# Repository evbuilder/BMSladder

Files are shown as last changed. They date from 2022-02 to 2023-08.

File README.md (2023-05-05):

# BMSladder
-----------
 BMS - cell at a time

This is an attempt at a single cell daisy chain Battery Management System. Emphasis is placed on minimum power draw and cost. Hopefully it is also reliable.

Most parts are over specified, however I worry that having the microcontroller powered directly from the cell could lead to bad things if the cell ever has a voltage spike on it. The type caused by a loose connection maybe especially bad.

Be warned.

Flashing the microcontroller
----------------------------
This uses a newer generation of ATtiny that is commonly used with Arduino. Current firmware uses Microchip Studio, and I have used a ATtiny416xplained demo board to flash the ATtiny202
Alternatively, firmware could be developed that uses Arduino IDE, with a programmer made as described here: https://github.com/SpenceKonde/AVR-Guidance/blob/master/UPDI/jtag2updi.md

History:
--------

v1.1
- incorporate uC pin swap mod
- improve connections

v1.0 Initial test production run. Mostly works. If you ever get one of these boards, check to see the modification is done to swap FAULT and EN pins.

Application: KiCad
Version: (5.1.10-1-10_14), release build

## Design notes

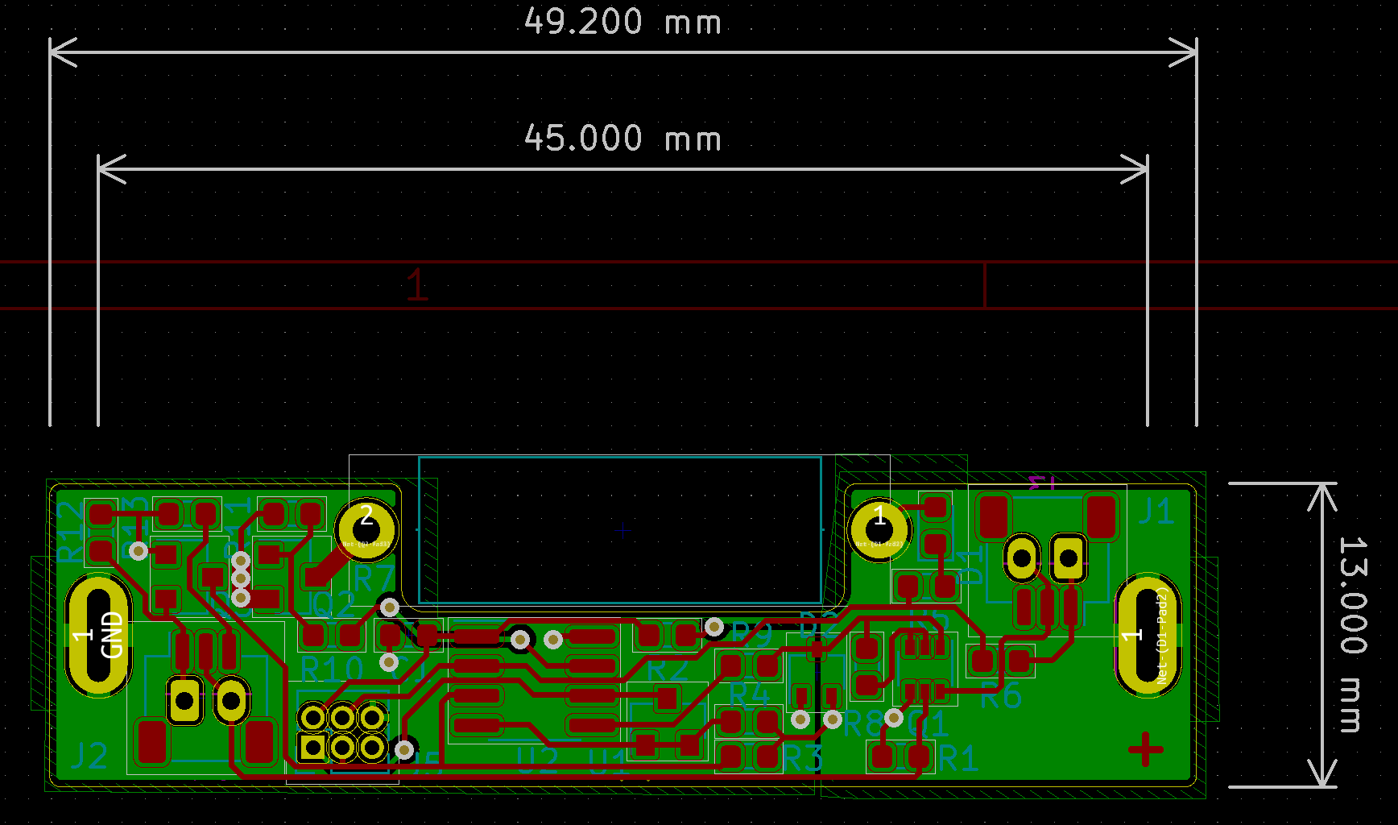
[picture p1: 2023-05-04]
BMSladder_pcb.png

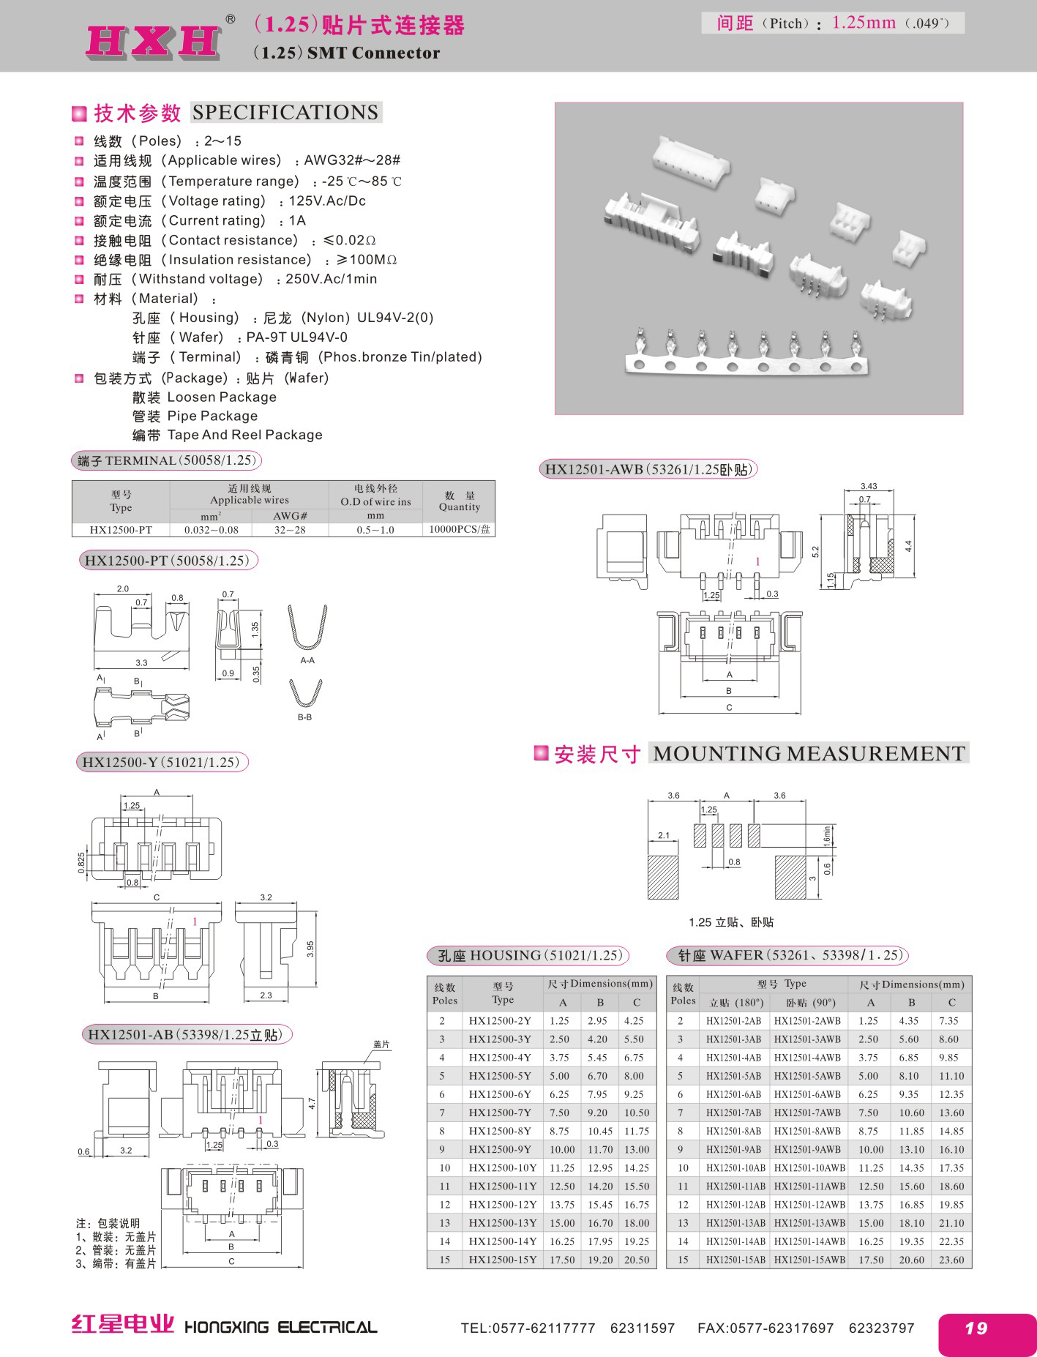
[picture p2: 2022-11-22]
Datasheets/HX12501 1.25mm connector system.jpg

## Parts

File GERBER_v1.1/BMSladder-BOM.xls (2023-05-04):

Designation | Designator | Footprint
SM03B-SRSS-TB(LF)(SN) | J1,J2 | JST_SH_SM03B-SRSS-TB_1x03-1MP_P1.00mm_Horizontal
RED LED | D1 | LED_0603_1608Metric
220k | R3,R8,R9,R11 | R_0603_1608Metric
ATTINY-202SSF | U2 | SOIC-8_3.9x4.9mm_P1.27mm
270k | R13 | R_0603_1608Metric
150k | R1,R6,R12 | R_0603_1608Metric
3K3 | R4,R5,R10 | R_0603_1608Metric
10R | R2 | R_0603_1608Metric
MMBT3904 | Q3 | SOT-23
SI3402-TP | Q2 | SOT-23
MMDT3946 | Q1 | SOT-363_SC-70-6
BAV99W | D2 | SOT-323_SC-70
1uF X7R 16V | C1 | C_0603_1608Metric

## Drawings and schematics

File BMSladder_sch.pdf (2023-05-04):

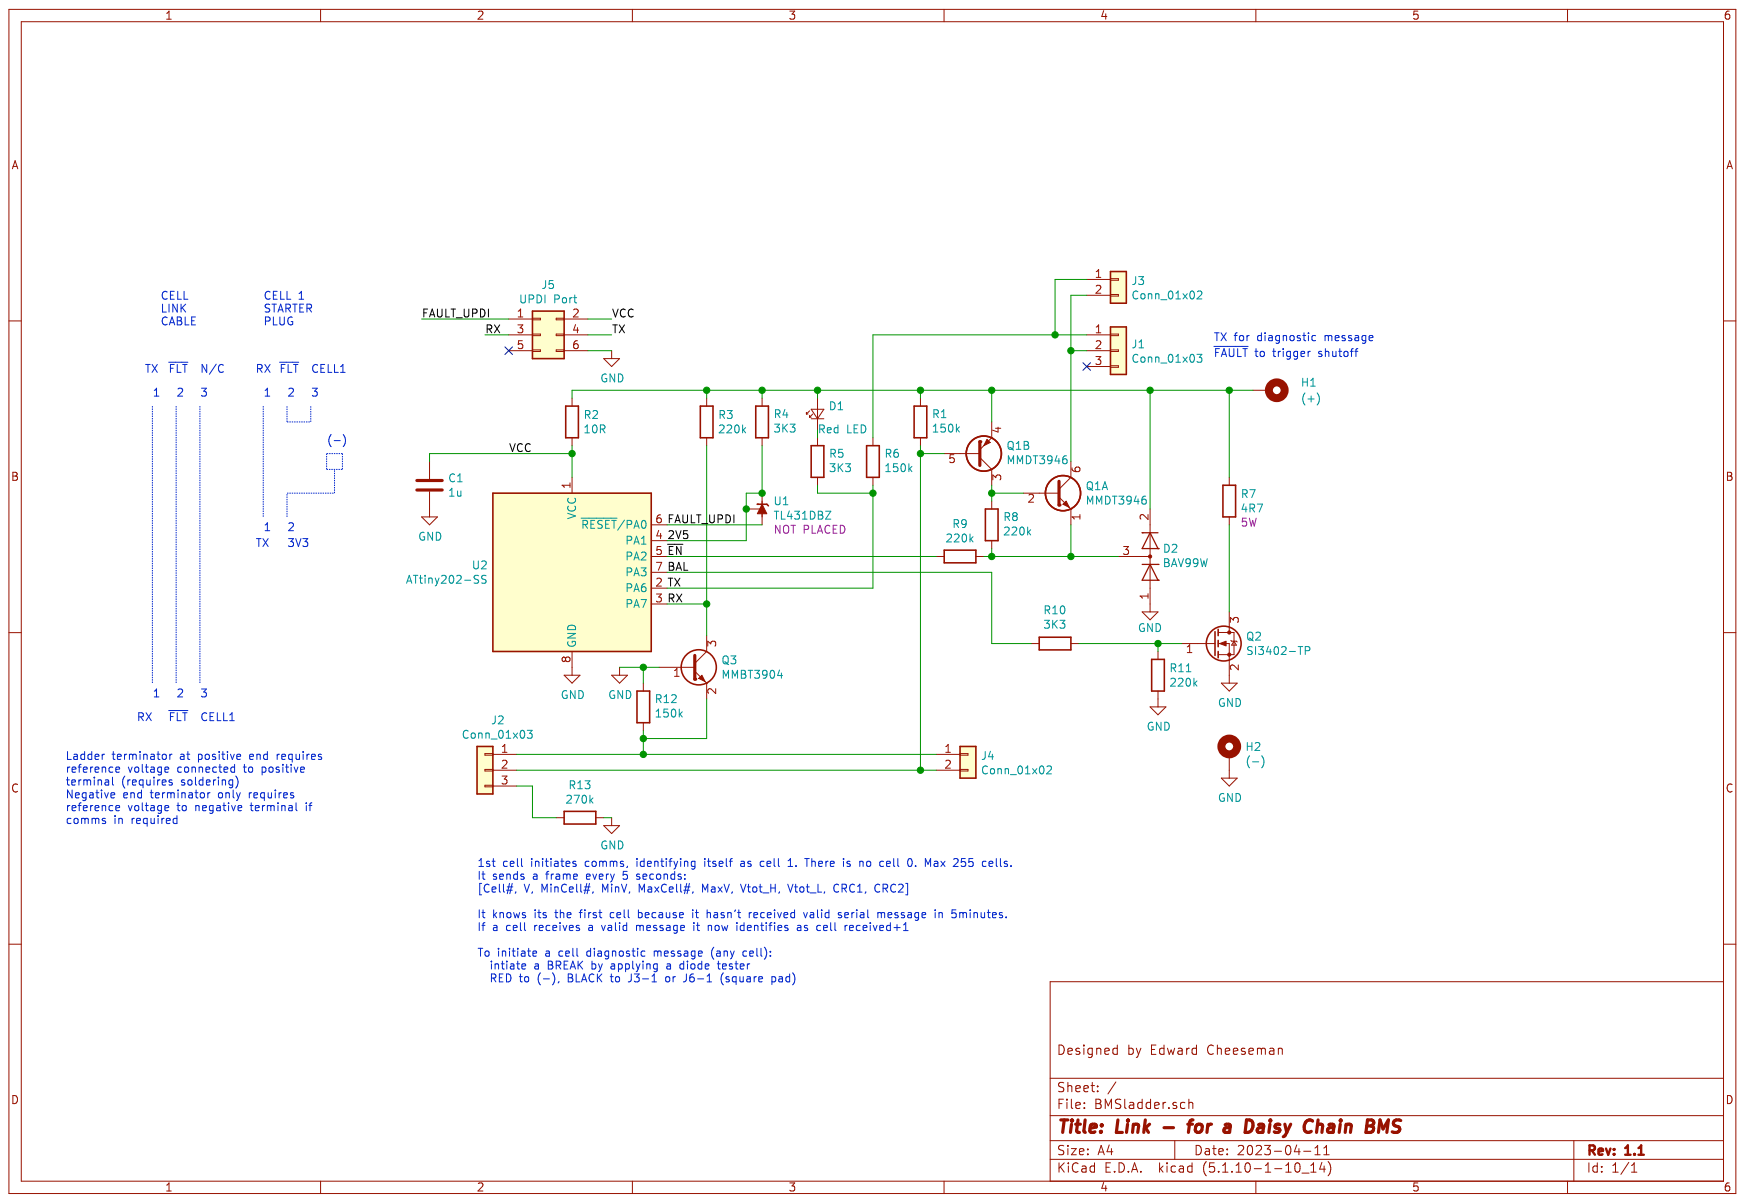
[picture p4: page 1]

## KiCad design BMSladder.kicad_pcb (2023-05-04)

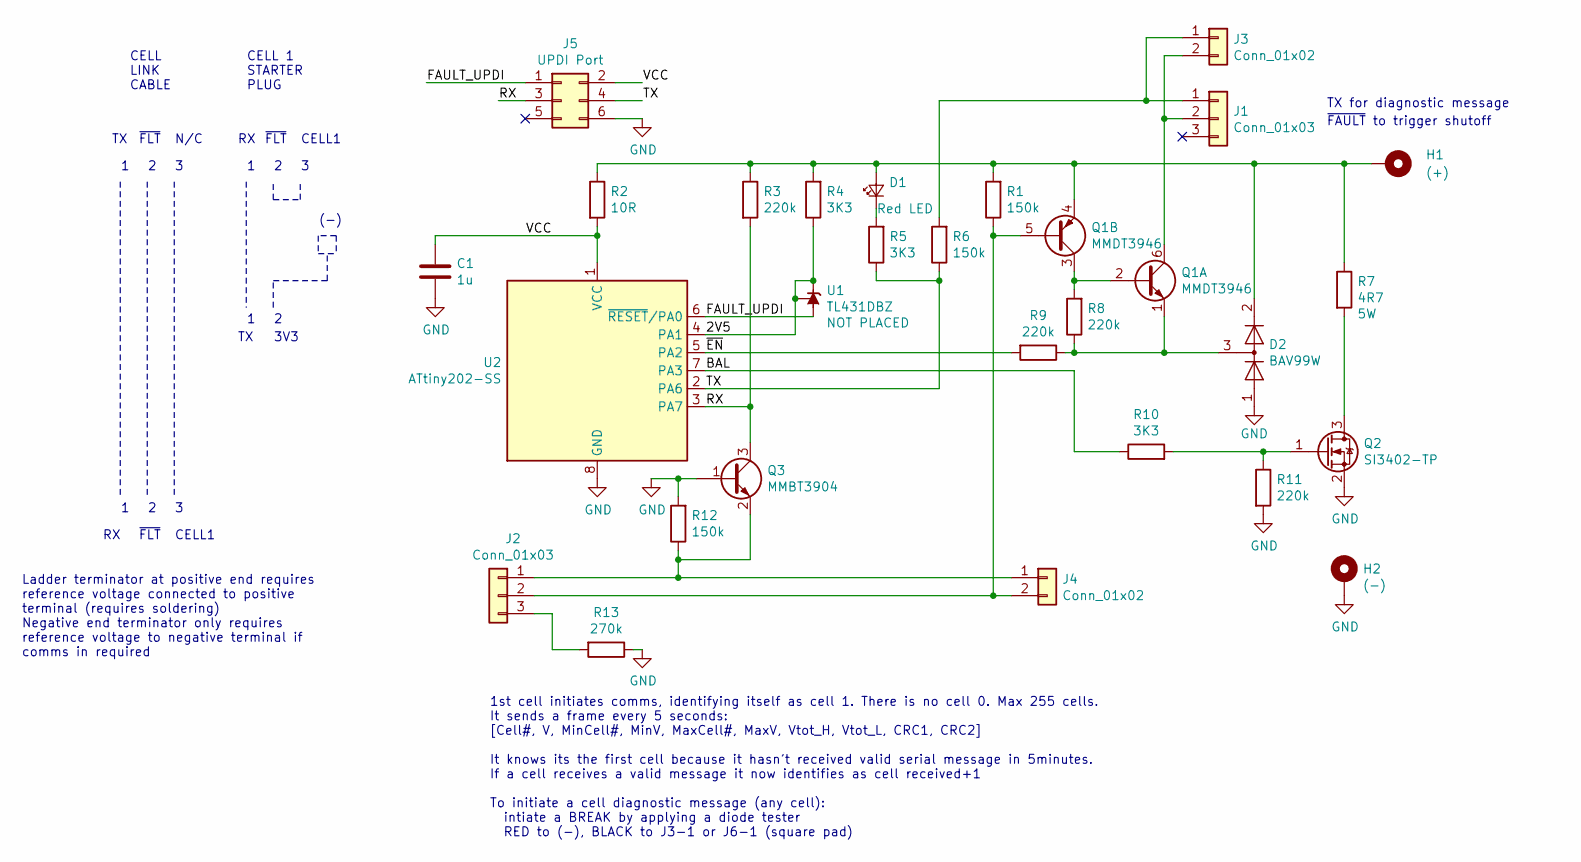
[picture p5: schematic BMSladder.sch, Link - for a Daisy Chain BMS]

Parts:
C1: 1u; C_0603_1608Metric
D1: Red LED; LED_0603_1608Metric
D2: BAV99W; SOT-323_SC-70
H1: (+); Terminal tag 3.2mm slot
H2: (-); Terminal tag 3.2mm slot
J1, J2: Conn_01x03; JST_SH_SM03B-SRSS-TB_1x03-1MP_P1.00mm_Horizontal
J3, J4: Conn_01x02; HY2.0mm2P_Header_Horizontal
J5: UPDI Port; PinHeader_2x03_P1.27mm_Vertical
Q1: MMDT3946; SOT-363_SC-70-6
Q2: SI3402-TP; SOT-23
Q3: MMBT3904; SOT-23
R1, R6, R12: 150k; R_0603_1608Metric
R2: 10R; R_0603_1608Metric
R3, R8, R9, R11: 220k; R_0603_1608Metric
R4, R5, R10: 3K3; R_0603_1608Metric
R7: 4R7; R_Axial_L17.0mm_D6.0mm_P22mm_Horizontal
R13: 270k; R_0603_1608Metric
U1: TL431DBZ; SOT-23
U2: ATtiny202-SS; SOIC-8_3.9x4.9mm_P1.27mm

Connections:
/2V5: R4.1, U1.1 (K), U1.2 (REF), U2.4 (PA1)
/BAL: R10.1, U2.7 (PA3)
/FAULT_UPDI: J5.1, U1.3 (A), U2.6 (~RESET~/PA0)
/RX: J5.3, Q3.3 (C), R3.2, U2.3 (PA7)
/TX: J5.4, R5.1, R6.1, U2.2 (PA6)
/VCC: C1.1, J5.2, R2.2, U2.1 (VCC)
/~EN: R9.2, U2.5 (PA2)
GND: C1.2, D2.1 (K), H2.1, J5.6, Q2.2 (S), Q3.1 (B), R11.2, R12.2, R13.1, U2.8 (GND)
unnamed: D1.1 (K), R5.2
unnamed: D1.2 (A), D2.2 (A), H1.1, Q1.4 (E2), R1.2, R2.1, R3.1, R4.2, R7.1
unnamed: D2.3 (K), Q1.1 (E1), R8.1, R9.1
unnamed: J1.1, J3.1, R6.2
unnamed: J1.2, J3.2, Q1.6 (C1)
unnamed: J2.1, J4.1, Q3.2 (E), R12.1
unnamed: J2.2, J4.2, Q1.5 (B2), R1.1
unnamed: J2.3, R13.2
unnamed: Q1.2 (B1), Q1.3 (C2), R8.2
unnamed: Q2.1 (G), R10.2, R11.1
unnamed: Q2.3 (D), R7.2

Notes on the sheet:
1st cell initiates comms, identifying itself as cell 1. There is no cell 0. Max 255 cells. It sends a frame every 5 seconds: [Cell#, V, MinCell#, MinV, MaxCell#, MaxV, Vtot_H, Vtot_L, CRC1, CRC2] It knows its the first cell because it hasn’t received valid serial message in 5minutes. If a cell rece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
TX for diagnostic message
~FAULT~ to trigger shutoff
N/C
~FLT
CELL1
CELL LINK CABLE
CELL 1 STARTER PLUG
Ladder terminator at positive end requires reference voltage connected to positive terminal (requires soldering) Negative end terminator only requires reference voltage to negative terminal if comms in required
(-)
3V3

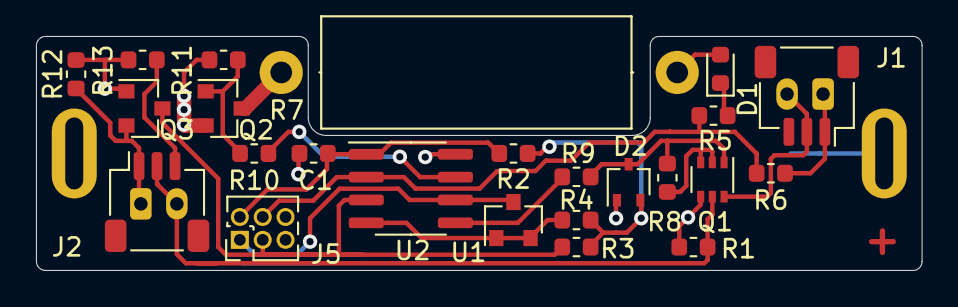
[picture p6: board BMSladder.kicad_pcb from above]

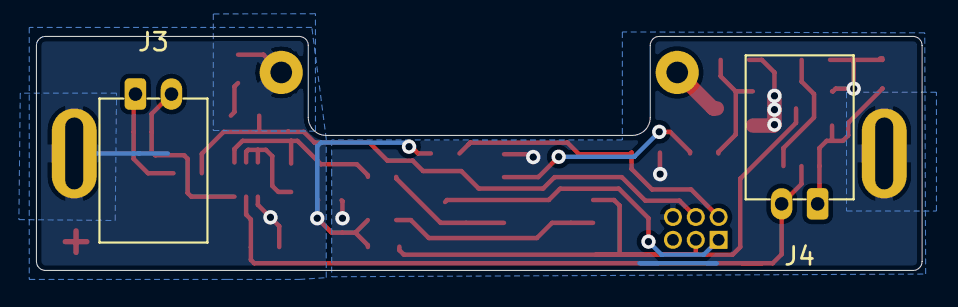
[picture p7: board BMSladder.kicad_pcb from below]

Board: 2 copper layers, 49.2 x 13.0 mm, 28 parts (2 on the bottom side), 19 nets.

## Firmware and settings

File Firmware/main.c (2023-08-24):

/*
	Notes:
	Program written and compiled in Microchip studio V7.0.2542
	
	Fuse Configuration:
	
	BOD - Disabled, when in brown out, the power consumption goes to 100uA vs < 1uA in shutdown sleep mode.
	Reset Pin - Configured for GPIO mode (Note, this makes the chip no longer reprogrammable without getting hold of a 12V pulse programmer
	Watchdog - 8k cycles, 8.2 seconds, this code always runs, then sleeps and waits for the watchdog to trigger a reset, there is no "main loop" for power consumption optimization.
	Startup Time - 16ms
*/

#include <avr/io.h>
#include <stdbool.h>

#include "CellManagement.h"
#include "HardwareDefines.h"

#define F_CPU 3200000UL
#include "util/delay.h"

void InitializeIO(void)
{
	PORTA_PIN0CTRL = PORT_ISC_INPUT_DISABLE_gc;
	PORTA_DIR = BALANCE_PIN_MASK | TX_LED_PIN_MASK;
	PORTA_OUTSET = TX_LED_PIN_MASK; //Default LED state is off	
}

void InitializeBalancePWM()
{
	TCA0_SINGLE_PER = 1024;
	TCA0_SINGLE_CMP0 = 128; //12.5% duty cycle on the balance FET, period around 80ms
	TCA0_SINGLE_CTRLB = TCA_SINGLE_CMP0EN_bm | TCA_SINGLE_WGMODE_SINGLESLOPE_gc;
	TCA0_SINGLE_CTRLA = TCA_SINGLE_CLKSEL_DIV256_gc;
	TCA0_SINGLE_CTRLC = 0;
}

inline void IndicateFault(void)
{
	PORTA_OUTSET = REF2V5_ENABLE_REPURPOSED_AS_FAULT;
}

inline void IndicateNoFault(void)
{
	PORTA_OUTCLR = REF2V5_ENABLE_REPURPOSED_AS_FAULT;
}

inline void LedOn(void)
{
	PORTA_OUTCLR = TX_LED_PIN_MASK;
}

inline void LedOff(void)
{
	PORTA_OUTSET = TX_LED_PIN_MASK;
}

inline void ResetWatchdog(void)
{
	asm volatile(
	"WDR"
	);
}

void SleepDeep(void)
{
	SLPCTRL_CTRLA = SLPCTRL_SMODE_PDOWN_gc | SLPCTRL_SEN_bm;
	asm volatile(
	"SLEEP"
	);
}

void SleepIdle(void)
{
	SLPCTRL_CTRLA = SLPCTRL_SMODE_IDLE_gc | SLPCTRL_SEN_bm;
	asm volatile(
	"SLEEP"
	);
}

bool ConfigureFaultOutput(void)
{
	//Check the reset source, if it was a WDT, configure the Fault pin as GPIO output, if it was a POR we don't want to do this.
	//This gives us 8 seconds after connecting power to the board to be able to reprogram the device.
	if (RSTCTRL_RSTFR & RSTCTRL_WDRF_bm)
	{
		PORTA_DIRSET = REF2V5_ENABLE_REPURPOSED_AS_FAULT;
		return true;
	}
	return false;
}

void FlashLed(uint8_t numFlashes)
{
	while (numFlashes--)
	{
		ResetWatchdog();
		LedOn();
		_delay_ms(1);
		LedOff();
		if (numFlashes)
		{
			_delay_ms(500);
		}
	}
}

//void FlashVolts(uint32_t milliVolts)
//{
	//uint32_t wholeVolts = milliVolts / 1000;
	//uint32_t remainder = (milliVolts % 1000) / 100;
	//
	//FlashLed(wholeVolts);
	//_delay_ms(2000);
	//FlashLed(remainder);
//}

int main(void)
{
	ResetWatchdog();
	InitializeIO();
	InitializeBalancePWM();
	bool wasWatchdog = ConfigureFaultOutput();
	if(!wasWatchdog)
	{
		LedOn();
		while(1);
	}
	
	uint32_t cellVoltage;	
	cellStatus_t cellStatus = ManageCell(&cellVoltage);

	switch (cellStatus)
	{
		case CellStatusOverVoltage:
			IndicateFault();
			LedOn();
			SleepIdle();
			break;
		case CellStatusBalancing:
			//IndicateNoFault();
			IndicateFault(); //Fault output is going to be used to switch from CC to CV charge, so we want it high as soon as the first cell starts balancing
			FlashLed(2);
			SleepIdle();
			break;
		case CellStatusNormal:
			IndicateNoFault();
			FlashLed(1);
			break;
		case CellStatusUnderVoltage:
			//IndicateFault(); //Fault output is going to be used as a "overcharge indicator", so don't output fault condition for lower limit
			break;
	}

	SleepDeep();
}

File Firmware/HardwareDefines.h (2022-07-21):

/*
 * HardwareDefines.h
 *
 * Created: 7/05/2022 11:41:24 p.m.
 *  Author: Owner
 */ 


#ifndef HARDWAREDEFINES_H_
#define HARDWAREDEFINES_H_

#define FAULT_PIN_MASK (1 << 2)
#define REF2V5_PIN_MASK (1 << 1)
#define REF2V5_ENABLE_PIN_MASK (1 << 2)
#define BALANCE_PIN_MASK (1 << 3)
#define TX_LED_PIN_MASK (1 << 6)
#define RX_PIN_MASK (1 << 7)

#define REF2V5_ENABLE_REPURPOSED_AS_FAULT (1 << 2)


#endif /* HARDWAREDEFINES_H_ */

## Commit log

2022-02-22 Version 1
    [BMSladder-B_Cu.gbr, BMSladder-B_Mask.gbr, BMSladder-Edge_Cuts.gbr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]
2022-05-09 Update BMSladder.sch
    Added construction notes for further clarification
    [BMSladder.sch]
2022-11-22 Improve connections
    Most fiddly thing with v1.0 was the tail and connectors. changing to a surface mount connector (easy assembly), commonly available lead (if modified to remove one wire).
    Also, uC pin swap as per Heins mod
    [BMSladder.sch]
2023-05-04 old changes kept just in case
    not sure why
    [BMSladder.kicad_pcb, BMSladder.sch]
2023-05-04 2023 version
    Links now sockets on both ends, cable has two plugs. Swapped pins to make voltage reference programming pin
    [BMSladder-BOM.xls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]
2023-08-24 Tauis Settings
    LiFePO4 3.55V
    First time doesn't charge LED ON
    250mA current
    [CellManagement.c, main.c]
2024-05-28 remove old top rung
    [BMStopRung.kicad_pcb, BMStopRung.sch]

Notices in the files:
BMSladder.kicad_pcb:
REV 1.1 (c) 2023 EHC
